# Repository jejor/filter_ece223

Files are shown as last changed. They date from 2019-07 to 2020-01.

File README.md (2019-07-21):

# Filter Project for ECE223PSU/MCECS-2019

This repo contains information pertaining to a four branch 6th order passive Butterworth filters, with volume indicators, music box.
This project was completed to meet the 2018-2019 Electrical Engineering 221-223 sequence course requirements taught by Dr. Donald Duncan at Portland State University Maseeh College of Engineering and Computer Science - Electrical Engineering Program. 

View the project final report [here](/docs/finalreport.pdf) or by using the [google doc link](https://docs.google.com/document/d/1vV6OJEWidjzbffv2h6qe4K4YXA2pBC030I1_OhE0v94/edit?usp=sharing)

Note: Github documentation is currently in progress. Refer to the doc/finalreport.pdf until github documentation is completed.

FilterComplete

# Filter Project Information

## Project Purpose

The function of this project is to filter an audio signal and indicate, by light, the filtered frequency presence. The audio signal is filtered through four branches, each filter branch has its own adjustable volume/LED indicator which is activated when a signal passes through the filter branch. Below is the block diagram for the circuit design,

Fblockdiagram

## Project Parts

### [Audio/Input Signal](/docs/input_signal.md)

The audio signal (input signal) must fall within human range of hearing (typically 20-20000 Hz). The input into the system is a 3.5mm auxiliary audio connection. The audio is split into a stereo (binaural) and a mono (mixed) branch. The audio system design ensures that the music played over the speakers is kept separate as left and right audio channels and the filtered signal contains all the audio data. The audio data splits are made using NE5532 op amps used as buffers.

Note: The signal input is connected via screw terminal which allows for signal input modularity. Therefore, the 3.5mm auxiliary cable input into the filter branches and following volume indicator circuit can be removed to insert different signal generator.

### [Filter Branches](/docs/filters.md)

There are four 6th order passive Butterworth equal termination filters; one low-pass, two band-passes, and a high pass. These filters are routied and mounted on a custom designed PCB.

Note: 
- Low-Pass: < 200 Hz
- Band-Pass 1: 250 Hz to 4 kHz
- Band-Pass 2: 4.05 kHz to 9.95 kHz
- High-Pass: > 10 kHz

### [Volume Indicators](/docs/volume.md)

At the end of each filter branch is a LED volume indicator circuit. These circuits contain a series of LEDs and an LM3915 (resistor and comparator network). This circuit is used to indicate when an audio signal satisfies the filter frequencies and passes through that branch; the LM3915 is used to indicate the intensity (i.e. volume) of the signal. These circuits will have the display of two rows of 5 green, 3 yellow, and 2 red LEDs, totalling 20 LEDs per branch. There are a total of four volume indicators, each receiving an amplified signal from a filter.  The intensity of each volume indicator is controllable via a potentiometer controlling the gainstage on its respective filter. These circuits were routed and mounted on a custom designed PCB.

### [Power System](/docs/power.md)

Power Requirements:
- Op Amps, +18V and -18V
- LM3915, 12-20V
- LEDs, 3-5V
- Common Ground

To satisfy the power requirements the project uses a total of seven 9V batteries. These seven batteries are split between three battery packs with a common ground. The first battery pack powers all the op amp rails, it is four 9V batteries in series with a voltage divider to define a common ground and supply the +18V and -18V. The second battery pack powers the volume indicator circuit main power and contains two 9V batteries in series to supply +18V. The third battery pack powers the LEDs in the volume indicator circuit by using a single 9V and an LM317 voltage regulator to supply 3.3V.

### [Housing](/housing/README.md)

This project is housed within a pressed wood frame.

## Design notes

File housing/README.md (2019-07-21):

# Housing

The housing was designed using AutoDesk Fusion360 where each side was exported to .dxf file type. These files were then imported to RDWorks and then cut using a QD-1390 laser cutter.

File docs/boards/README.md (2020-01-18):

# EAGLE Boards

Made using EAGLE 9.3.2

There are two boards and schematic pairs in this folder. 

- lm3915LEDv.1.brd and lm3915LEDv.1.sch were both designed and manufacutured by Jennifer Jordan on May 2nd, 2019.
- filterboardsSMD-3.brd and filterboardsSMD-3.sch were both designed and manufactured by David Lay (dalay@pdx.edu) on May 29th, 2019.

The completed boards can be seen below,

- lm3915LEDv.1 Front
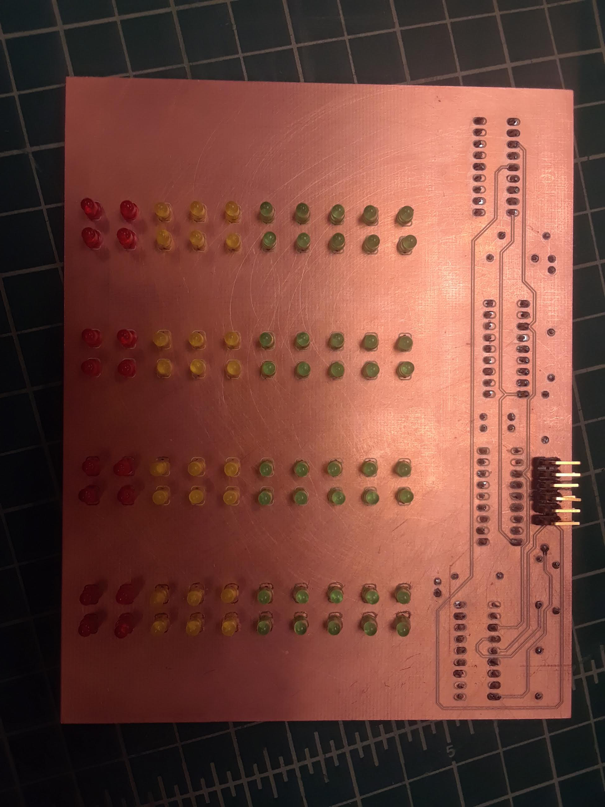
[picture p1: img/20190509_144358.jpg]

- Back
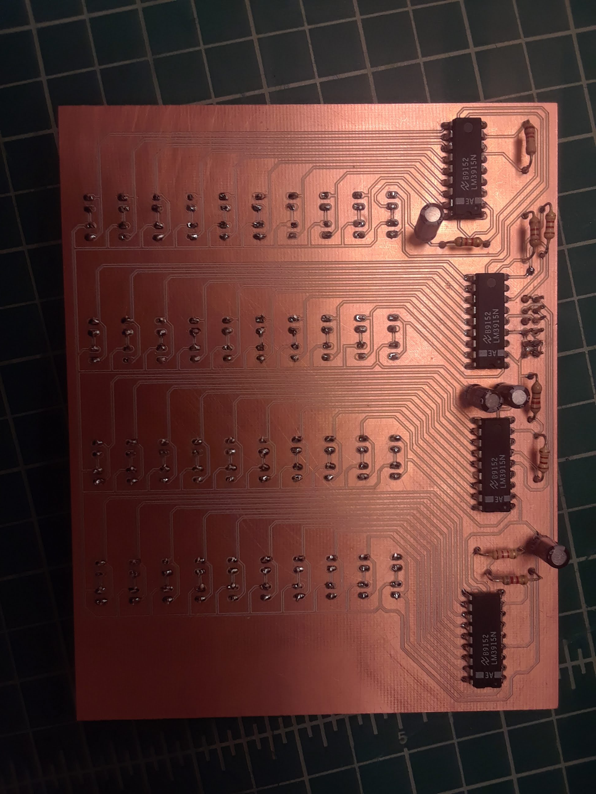
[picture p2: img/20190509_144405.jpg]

- filterboardsSMD-3 Front (credit: David Lay)
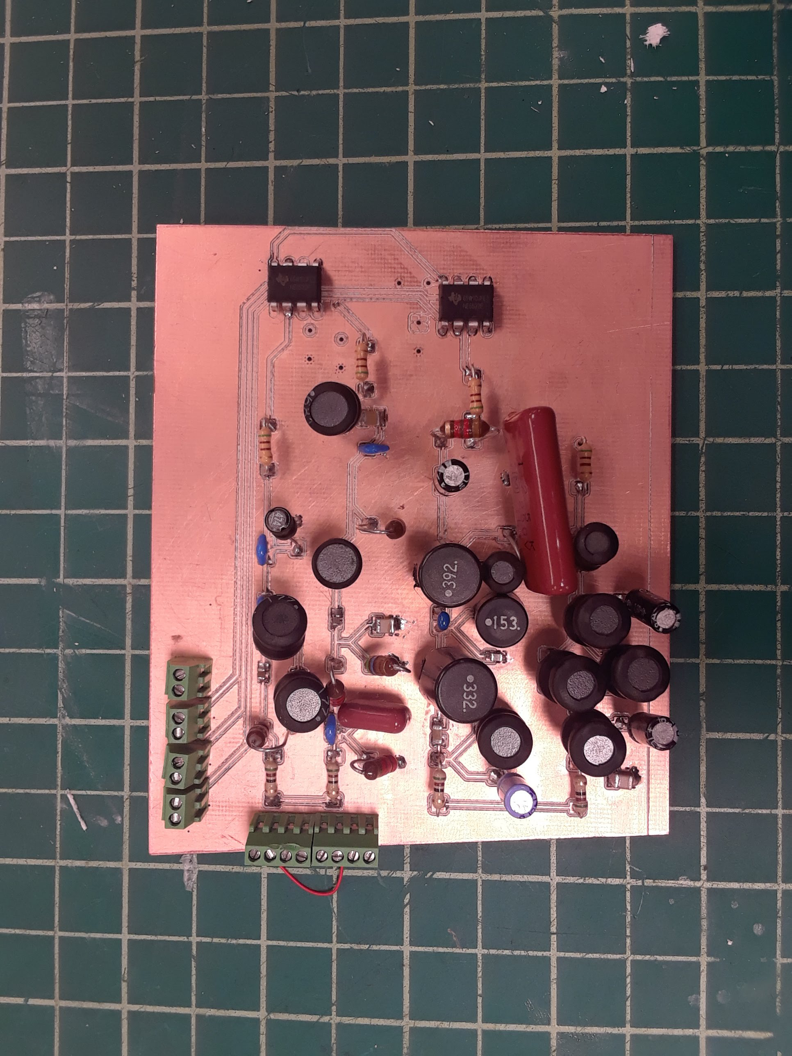
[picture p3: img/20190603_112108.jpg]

- Back (credit: David Lay)
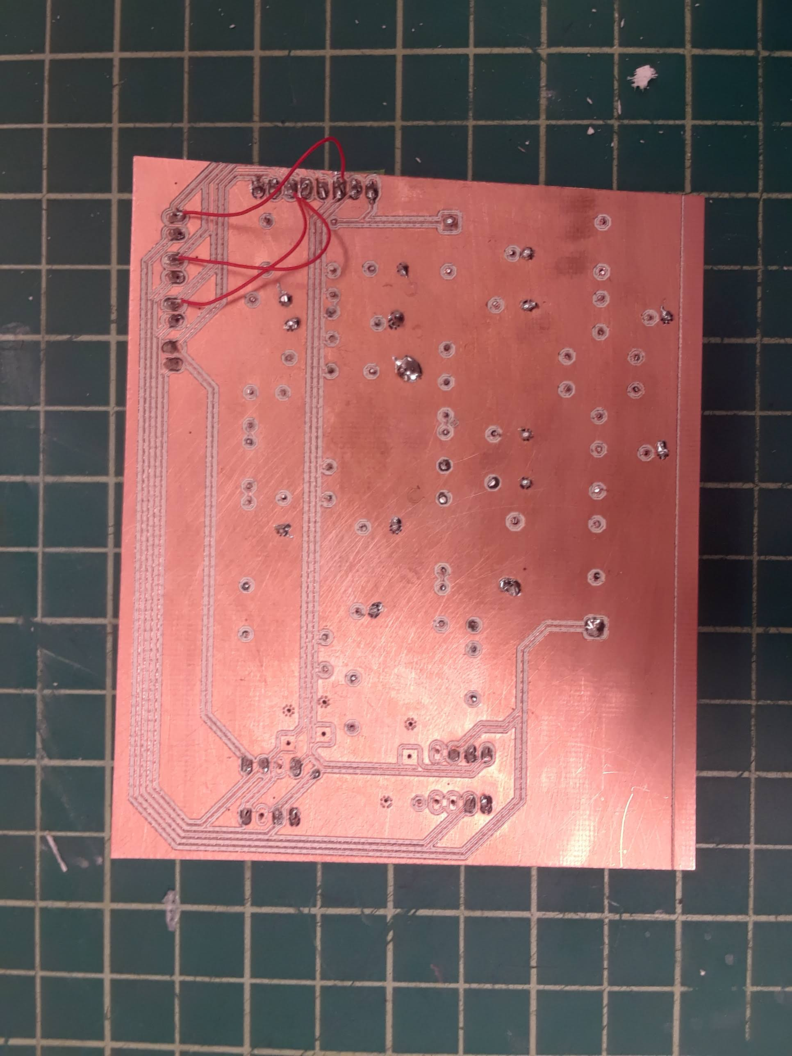
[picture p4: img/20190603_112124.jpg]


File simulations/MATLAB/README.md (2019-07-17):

# MATLAB Simulations

## Low-Pass Filter (< 200 Hz)

[Component Calculations](/simulations/MATLAB/Low_Pass/LPcomponentCalcs.md)

[Transfer Function Calculations](/simulations/MATLAB/Low_Pass/LPtf.md)

[MATLAB Code](/simulations/MATLAB/Low_Pass/LPml.m)

[Linear Analysis Results](/simulations/MATLAB/Low_Pass/LPla.pdf)

## Band-Pass 1 Filter (250 Hz - 4 kHz)

[Component Calculations](/simulations/MATLAB/Band_Pass1/BP1componentCalcs.md)

[Transfer Function Calculations](/simulations/MATLAB/Band_Pass1/BP1tf.md)

[MATLAB Code](/simulations/MATLAB/Band_Pass1/BP1ml)

[Linear Analysis Results](/simulations/MATLAB/Band_Pass1/BPla.pdf)

## Band-Pass 2 Filter (4.05 kHz - 9.95 kHz)

[Component Calculations](/simulations/MATLAB/Band_Pass2/BP2componentCalcs.md)

[Transfer Function Calculations](/simulations/MATLAB/Band_Pass2/BP2tf.md)

[MATLAB Code](/simulations/MATLAB/Band_Pass2/BP2ml)

[Linear Analysis Results](/simulations/MATLAB/Band_Pass2/BP2la.pdf)

## High-Pass Filter (> 10 kHz)

[Component Calculations](/simulations/MATLAB/High_Pass/HPcomponentCalcs.md)

[Transfer Function Calculations](/simulations/MATLAB/High_Pass/HPtf.md)

[MATLAB Code](/simulations/MATLAB/High_Pass/HPml.m)

[Linear Analysis Results](/simulations/MATLAB/High_Pass/HPla.pdf)

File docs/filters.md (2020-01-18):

# Filter Branches

There are four filters used in this circuit, one low-pass, one high pass, and two band-pass. All four filters are 6th order passive Butterworth equal termination filters. The low-pass filter has a set cutoff frequency of 200 Hz, the first band-pass filter has a set pass band between 250 Hz to 4 kHz, the second band-pass filter has a set pass band between 4.05 kHz to 9.95 kHz, and the high-pass filter has a set frequency cutoff of 10 kHz. At the output of each filter there is an operational amplifier with an adjustable gain (using a potentiometer). Per the LTspice simulations, the gain for this op amp should indicate no filter signal output to a maximum gain of 200. With the real component values, all four filter branches have less than a 7% difference from the set cutoff frequencies. These circuits were routed and assembled on a PCB.

For More info see the filter diagrams [here](docs/boards/README.md)

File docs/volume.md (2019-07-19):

# Volume Indicator Circuit

At the end of each filter branch is a LED volume indicator circuit. These circuits contain a series of LEDs and an [LM3915](http://pdf.datasheetcatalog.com/datasheet/nationalsemiconductor/DS005104.PDF) (resistor and comparator network). This circuit is used to indicate when an audio signal satisfies the filter frequencies and passes through that branch; the LM3915 is used to indicate the intensity (i.e. volume) of the signal. 

These circuits have the display of two rows of 5 green, 3 yellow, and 2 red LEDs, totalling 20 LEDs per branch and a total of 80 LEDs for the full circuit. There are four volume indicators, each receiving an amplified signal from a filter.  The intensity of each volume indicator is controllable via a potentiometer controlling the gainstage on its respective filter. These circuits were routed and mounted on a custom designed PCB.

volumeindicatorschematic

volumeindicatorboard

volumeindicatorpcbfront

volumeindicatorpcbback

## Power Pack

This circuit is powered by [power pack 2](/docs/power.md) which supplies +18V to the four LM3915 and also supplies +3.3V to the 80 LEDs.

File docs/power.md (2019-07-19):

# Power System

Due to project deadlines, the current power system for this project has a lot of room for improvement. The system design meets all the power requirements but the efficiency could be improved. To satisfy the power requirements the project uses a total of seven 9V batteries. These seven batteries are split between three battery packs with a common ground. 

The power requirements are as follows:

- Eight NE5532 op amps which require +18V and -18V
- Four LM3915s which require 12-20V
- Four LED rows totalling 80 LEDs which require 3-5V

The first battery pack powers all the op amp rails, it is four 9V batteries in series with a voltage divider to define a common ground and supply the +18V and -18V, see the circuit diagram below.

powerpack1

The second battery pack powers the volume indicator circuit main power and contains two 9V batteries in series to supply +18V. There is also a power switch mounted to the housing that is placed within this circuit. The power switch has three states, I, Off, and II. There is a diode, 1N4148, which prevents the mode from being triggered when I is selected and allows the mode to be changed when selecting II, see below.

powerpack2

The third battery pack powers the LEDs in the volume indicator circuit by using a single 9V and an LM317 voltage regulator to supply 3.3V. The equation used to calculate the Vout value of the LM317 is Vout=1.25*(1+R2R1). The resistor values were calculated using the prior equation where R1=110 and R2=180.

powerpack3

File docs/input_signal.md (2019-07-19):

# Audio/Input Signal 

The audio is fed through a 3.5mm auxillary cable and is split into a stereo (binaural) and a mono (mixed) branch. The audio system design ensures that the music played over the speakers is kept separate as left and right audio channels and the filtered signal contains all the audio data. The audio data splits are made using [NE5532](http://www.ti.com/lit/ds/symlink/ne5532.pdf) op amps used as buffers.

audiodiagram

To filter an audio signal (using the above circuit) the mono-signal is fed into pin 8 in the below diagram,

signalinputdiagram

It can be seen that the input signal to the filter circuit is interchangable using the terminal block as the signal input,

signalinputphoto

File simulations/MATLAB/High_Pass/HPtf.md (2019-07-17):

## High Pass Transfer Function Calculation

Given the Factors of Polynomials for 6th order filters, 

Factors_of_Polynomials

the following transfer function for high-pass filter was calculated,
	HLP(s)=G0B6(s), where G0=1
	HLP(s)=1(s2+0.5176s+1)(s2+1.4142s+1)(s2+1.9319s+1)
Next, the transfer function for the high-pass is calculated given the LPF-to-HPF transformation where the band-pass filter transfer function is H(cs) and c=10000*2= 62831.85 rad/s. Such that, 
	cs=62831.85s
	HHP(s)=s9s9+2.428e05s8+2.947e10s7+2.268e15s6+1.163e20s5+3.784e24s4+6.153e28s3

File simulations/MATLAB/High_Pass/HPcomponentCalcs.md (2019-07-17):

## High-Pass Component Calculations

The high-pass filter in this circuit is a 6th order Butterworth equal termination filter. 
The cutoff frequency is set to 10 kHz. 
Given the Butterworth equal termination High-Pass Prototype Element chart, 

High_Pass_Prototype_Element_Chart

and the following diagram,

High_Pass_Basic_Diagram

Where, RS=RL=50  and fc=10000 Hz the following component values are calculated,

Ideal Component Values
Real Component Values
L1
1.535883 mH
1.8 mH
C2
225 nF
220 nF
L3
412.221 H
220 H+220 H=440 H
C4
165 nF
150 nF
L5
562.626 H
 470  H 
C6
614 nF
 680 nF

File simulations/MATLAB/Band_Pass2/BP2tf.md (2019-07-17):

## Band-Pass 2 Transfer Function Calculations

Given the Factors of Polynomials for 6th order filters, 

Factors_of_Polynomials

the following transfer function for band-pass 2 filter was calculated,
	HLP(s)=G0B6(s), where G0=1
	HLP(s)=1(s2+0.5176s+1)(s2+1.4142s+1)(s2+1.9319s+1)
Next, the transfer function for the band-pass is calculated given the LPF-to-BPF transformation where the band-pass filter transfer function is H(Q(s0+0s)), the Q-factor is Q=0, the resonant frequency is 0=12, the absolute bandwidth is =(2-1), 1=4050*2=25446.9 rad/s, and 2=9950*2=62517.69 rad/s. Such that,
	=(2-1)=62517.69-25446.9=37070.79 rad/s
	0=12=25446.9*62517.69=39885.9 rad/s
	Q=0=39885.937070.79=1.0759
	HBP1(s)=2.555e41s99.842e13s15+1.41e19s14+1.949e24s13+1.58e29s12+1.155e34s11+6.022e38s10
		2.793e43s9+9.58e47s8+2.923e52s7+6.361e56s6+1.248e61s5+1.437e65s4+1.596e69s3

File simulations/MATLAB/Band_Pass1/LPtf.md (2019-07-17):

## Low Pass Transfer Function Calculations

Given the Factors of Polynomials for 6th order filters, 

Factors_of_Polynomials

the following transfer function for the band-pass 1 filter was calculated,
	HLP(s)=G0B6(s), where G0=1
	HLP(s)=1(s2+0.5176s+1)(s2+1.4142s+1)(s2+1.9319s+1)
Next, the transfer function for the band-pass is calculated given the LPF-to-BPF transformation where the band-pass filter transfer function is H(Q(s0+0s)), the Q-factor is Q=0, the resonant frequency is 0=12, the absolute bandwidth is =(2-1), 1=250*2=1570.8 rad/s, and 2=4000*2=25132.74 rad/s. Such that,
	=(2-1)=25132.74-1570.8=23561.94 rad/s
	0=12=1570.8*25132.74=6283.19 rad/s
	Q=0=23561.946283.19=0.267
	HBP1(s)=1.526e34s98.987e07s15+8.171e12s14+3.928e17s13+1.232e22s12+2.665e26s11+3.901e30s10
		3.509e34s9+1.54e38s8+4.153e41s7+7.58e44s6+9.54e47s5+7.836e50s4+3.402e53s3

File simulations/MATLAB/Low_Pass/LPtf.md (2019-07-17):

## Low Pass Transfer Function Calculation

Given the Factors of Polynomials for 6th order filters, 

Factors_of_Polynomials

the following transfer function for the low-pass filter was calculated,
	HLP(s)=G0B6(s), where G0=1,B6(s)=1(s2+0.5176s+1)(s2+1.4142s+1)(s2+1.9319s+1),  andc=2*200=1256.6064 rad/s
	HLP(s)=G0B6(sc)=1((sc)2+0.5176(sc)+1)((sc)2+1.4142(sc)+1)((sc)2+1.9319(sc)+1)
	HLP(s)=1((s1256.6)2+0.5176(s1256.6)+1)((s1256.6)2+1.4142(s1256.6)+1)((s1256.6)2+1.9319(s1256.6)+1)
HLP(s)=12.53636*10-19*s6+1.23201*10-15*s5+2.99159*10-12s4+4.60529*10-9s3+4.72605*10-6s2+0.00307473*s+1

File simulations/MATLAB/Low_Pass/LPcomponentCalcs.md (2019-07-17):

## Low Pass Component Calculations

The flow-pass filter in this circuit is a 6th order Butterworth equal termination filter. The cutoff frequency is 200 Hz. 
Given the Butterworth equal termination Low-Pass Prototype Element chart

Low_Pass_Prototype_Element_Chart
, and the following diagram,

Low_Pass_Basic_Diagram

Where, RS=RL=50  and the following component values are calculated,

Ideal Component Values
Actual Component Values
C1
8.244 F
8.2 F
L2
56.26 mH
56 mH
C3
30.749 F
33 F
L4
76.87 mH
1156 mH+156 mH+56mH = 84 mH
C5
22.5 F
22 F
L6
20.6 mH
22 mH

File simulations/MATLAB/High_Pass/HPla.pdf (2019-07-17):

%Transfer Function Analysis for High-Pass 6th Order Butterworth Filter %ECE223 Sp19, Jennifer Jordan & David Lay

s = tf('s');
x = (62831.85/s); %LP to HP transformation condition
H = 1/((x^2+.5176*x+1)*(x^2+1.4142*x+1)*(x^2+1.9319*x+1)) %Figures:
figure(1);
bode(H);
title('High-Pass Butterworth Filter Bode Plot'); figure(2);
impulse(H);
title('High-Pass Butterworth Filter Impulse Response'); figure(3);
step(H);
title('High-Pass Butterworth Filter Step Response'); figure(4);
pzplot(H);
title('High-Pass Butterworth Filter Pole-Zero Plot');

H =

s^9

s^9 + 2.428e05 s^8 + 2.947e10 s^7 + 2.268e15 s^6 + 1.163e20 s^5

+ 3.784e24 s^4 + 6.153e28
s^3

Continuous-time transfer function.

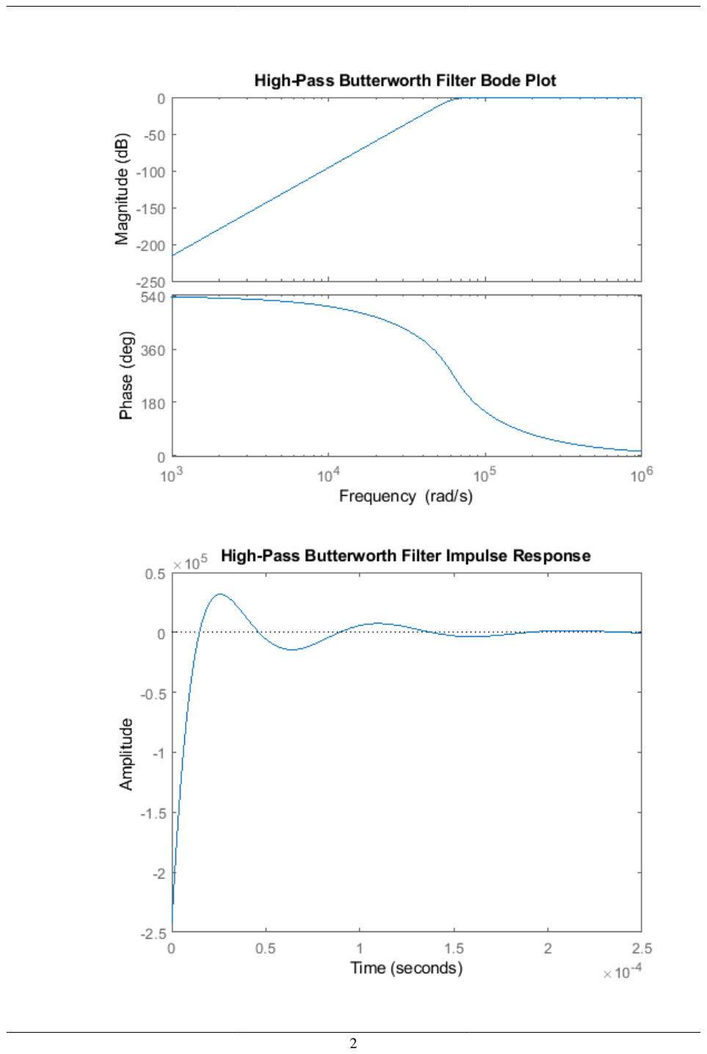
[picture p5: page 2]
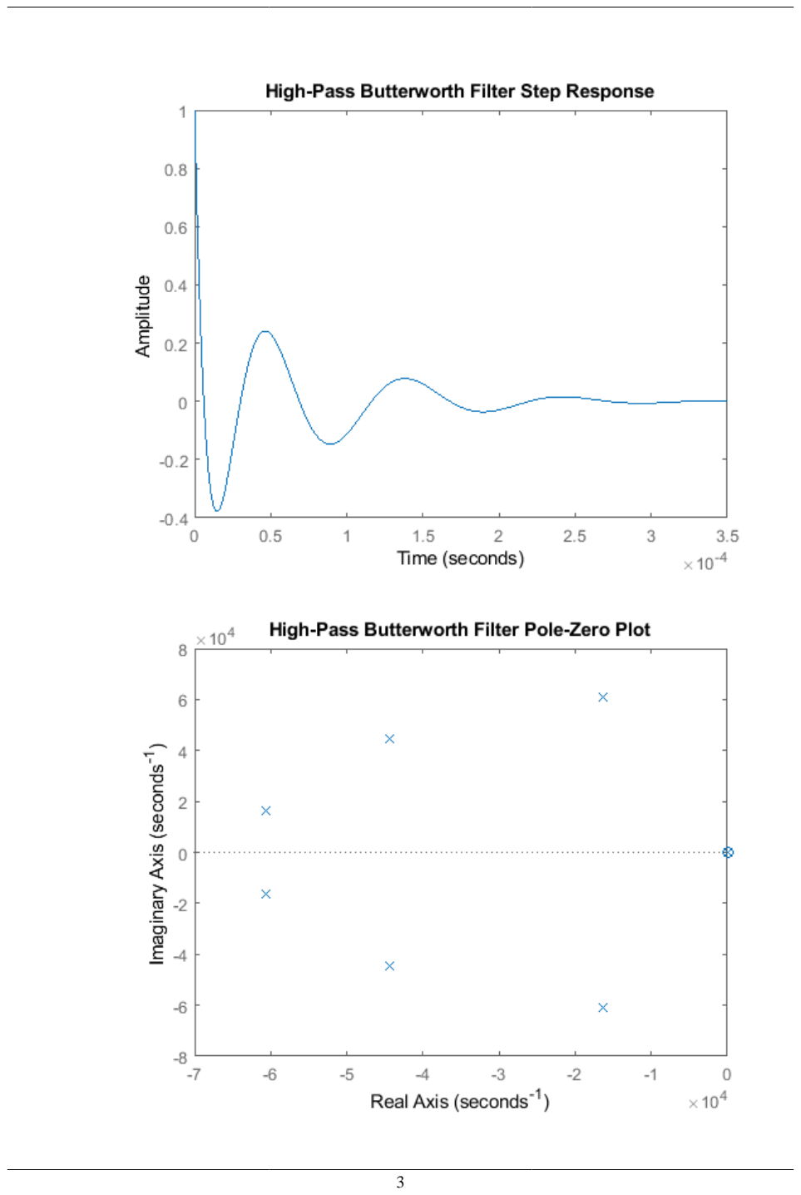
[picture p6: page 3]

Published with MATLAB® R2018b

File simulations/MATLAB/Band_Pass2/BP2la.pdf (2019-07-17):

%Transfer Function Analysis for Band-Pass 2 6th Order Butterworth Filter
%ECE223 Sp19, Jennifer Jordan & David Lay

s = tf('s');
x = (1.0759*((s/39885.9)+(39885.9/s))); %LP to BP transformation condition
H = 1/((x^2+.5176*x+1)*(x^2+1.4142*x+1)*(x^2+1.9319*x+1)) %Figures:
figure(1);
bode(H);
title('Band-Pass 2 Butterworth Filter Bode Plot'); figure(2);
impulse(H);
title('Band-Pass 2 Butterworth Filter Impulse Response'); figure(3);
step(H);
title('Band-Pass 2 Butterworth Filter Step Response'); figure(4);
pzplot(H);
title('Band-Pass 2 Butterworth Filter Pole-Zero Plot');

H =

2.555e41 s^9

9.842e13 s^15 + 1.41e19 s^14 + 1.949e24 s^13 + 1.58e29 s^12 +
1.155e34 s^11

+ 6.022e38 s^10 + 2.793e43 s^9 + 9.58e47 s^8 + 2.923e52 s^7

+ 6.361e56 s^6 + 1.248e61 s^5 + 1.437e65 s^4 + 1.596e69 s^3

Continuous-time transfer function.

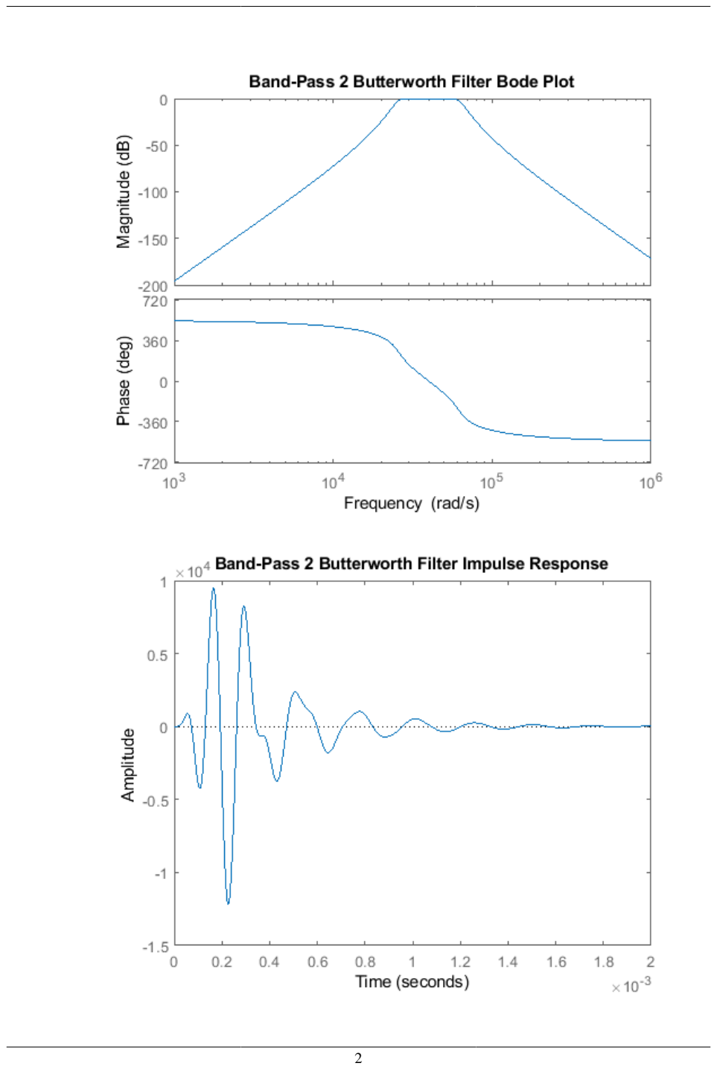
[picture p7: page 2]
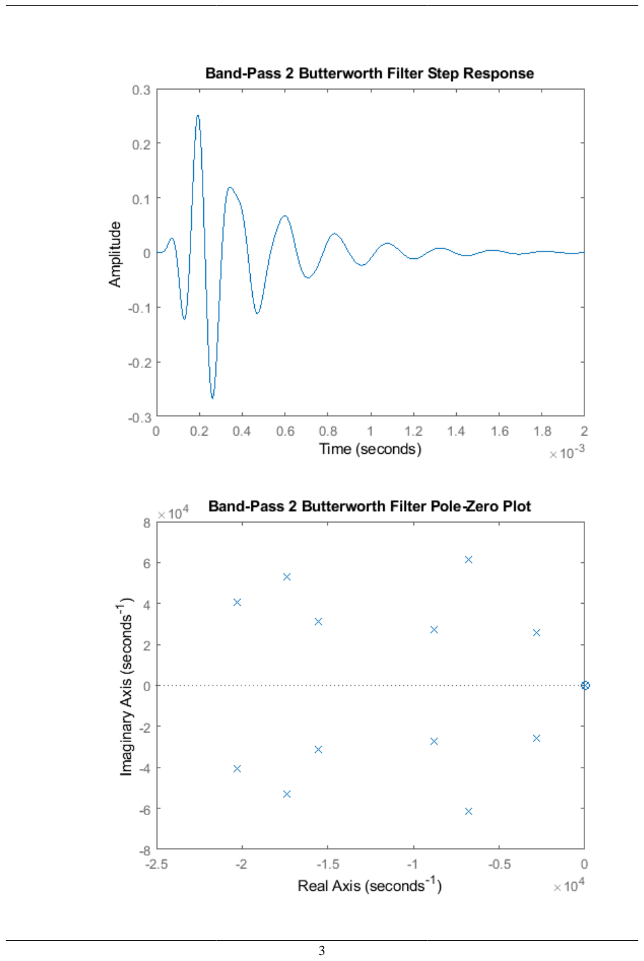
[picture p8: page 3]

Published with MATLAB® R2018b

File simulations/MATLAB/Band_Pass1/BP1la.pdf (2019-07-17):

%Transfer Function Analysis for Band-Pass 1 6th Order Butterworth Filter
%ECE223 Sp19, Jennifer Jordan & David Lay

s = tf('s');
x = (.267*((s/6283.19)+(6283.19/s))); %LP to HP transformation condition
H = 1/((x^2+.5176*x+1)*(x^2+1.4142*x+1)*(x^2+1.9319*x+1)) %Figures:
figure(1);
bode(H);
title('Band-Pass 1 Butterworth Filter Bode Plot'); figure(2);
impulse(H);
title('Band-Pass 1 Butterworth Filter Impulse Response'); figure(3);
step(H);
title('Band-Pass 1 Butterworth Filter Step Response'); figure(4);
pzplot(H);
title('Band-Pass 1 Butterworth Filter Pole-Zero Plot');

H =

1.526e34 s^9

8.987e07 s^15 + 8.171e12 s^14 + 3.928e17 s^13 + 1.232e22 s^12

+ 2.665e26 s^11 + 3.901e30 s^10 + 3.509e34 s^9 + 1.54e38 s^8

+ 4.153e41 s^7 + 7.58e44 s^6 + 9.54e47 s^5 + 7.836e50 s^4

+ 3.402e53
s^3

Continuous-time transfer function.

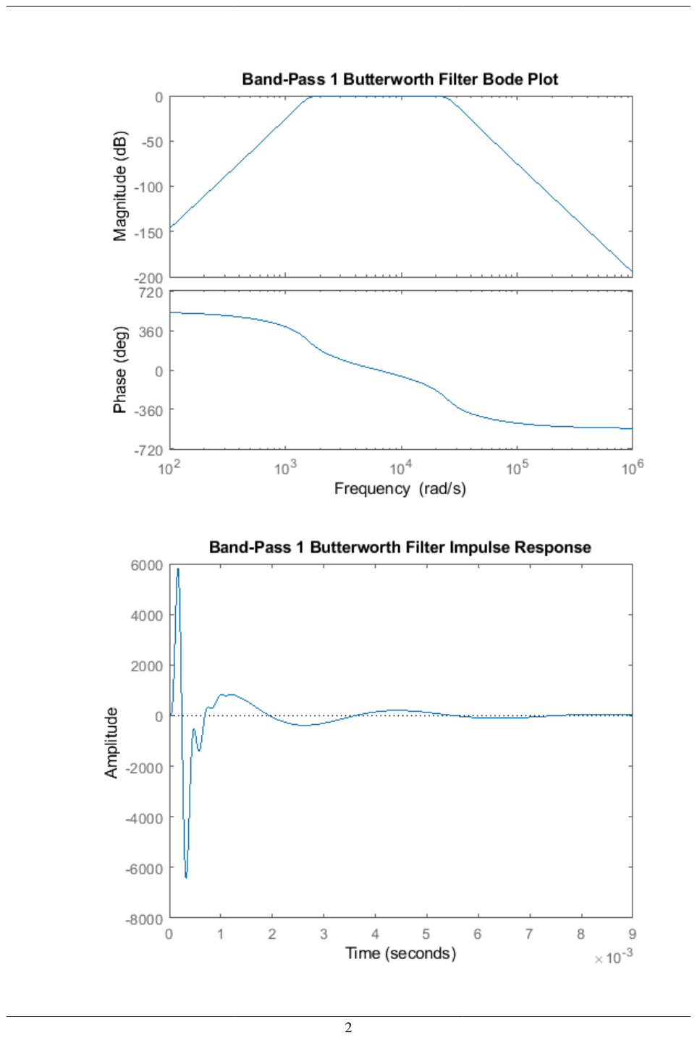
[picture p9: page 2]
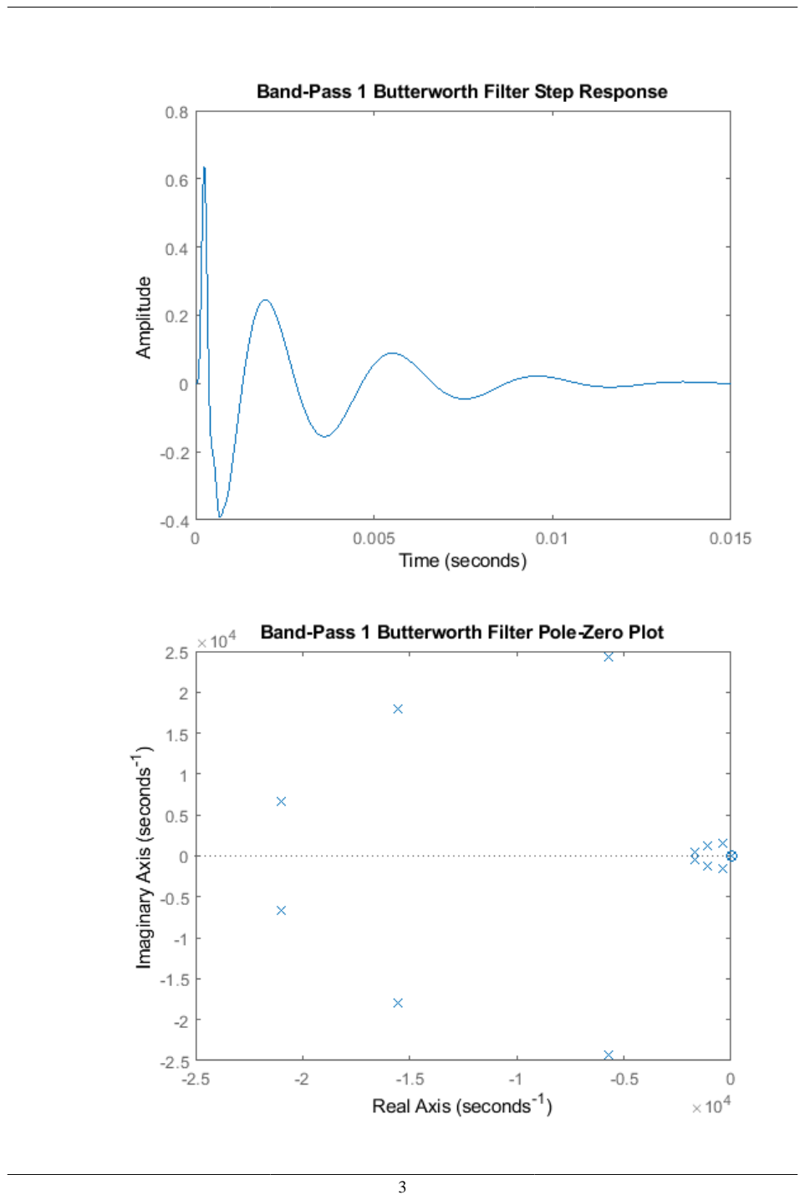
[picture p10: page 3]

Published with MATLAB® R2018b

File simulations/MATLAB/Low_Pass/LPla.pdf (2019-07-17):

%Transfer Function Analysis for High-Pass 6th Order Butterworth Filter %ECE223 Sp19, Jennifer Jordan & David Lay
s = tf('s');
H = 1/
(2.53636*10^-19*s^6+1.23201*10^-15*s^5+2.99159*10^-12*s^4+4.60529*10^-9*s^3+4.72605*10^-6*s^2+0.00307473*s +1)

%Figures:
figure(1);
bode(H);
title('Low-Pass Butterworth Filter Bode Plot'); figure(2);
impulse(H);
title('Low-Pass Butterworth Filter Impulse Response'); figure(3);
step(H);
title('Low-Pass Butterworth Filter Step Response'); figure(4);
pzplot(H);
title('Low-Pass Butterworth Filter Pole-Zero Plot');

H =

1

2.536e-19 s^6 + 1.232e-15 s^5 + 2.992e-12 s^4 + 4.605e-09 s^3

+ 4.726e-06 s^2 + 0.003075 s + 1

Continuous-time transfer function.

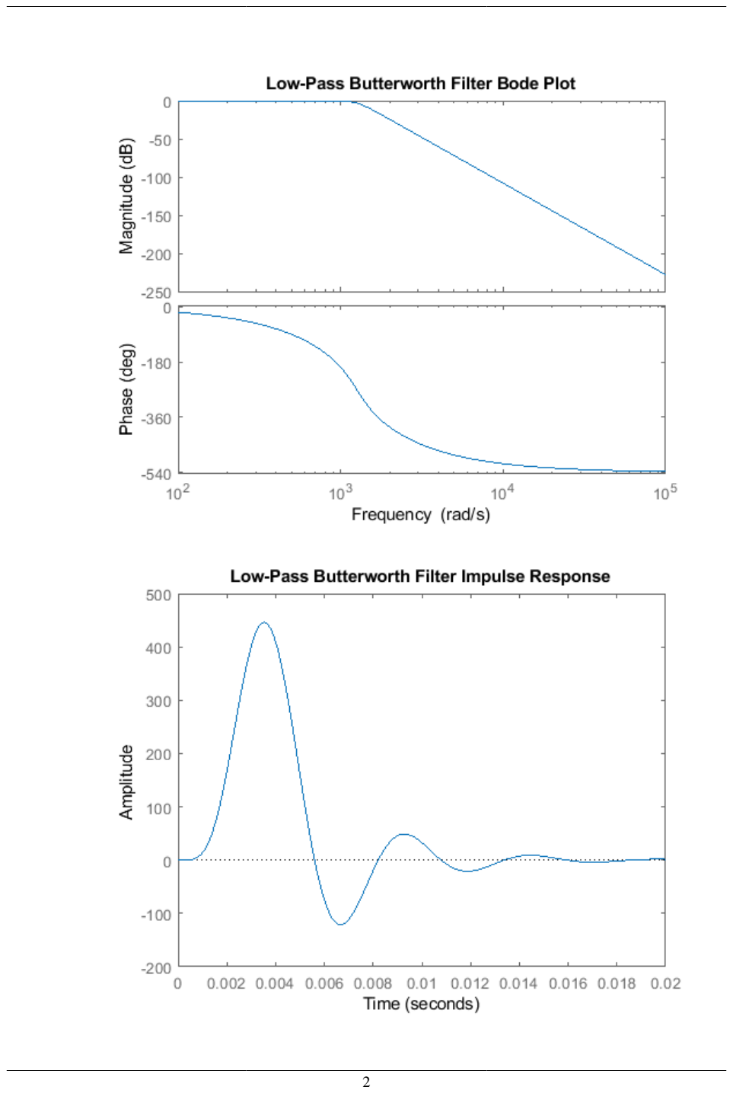
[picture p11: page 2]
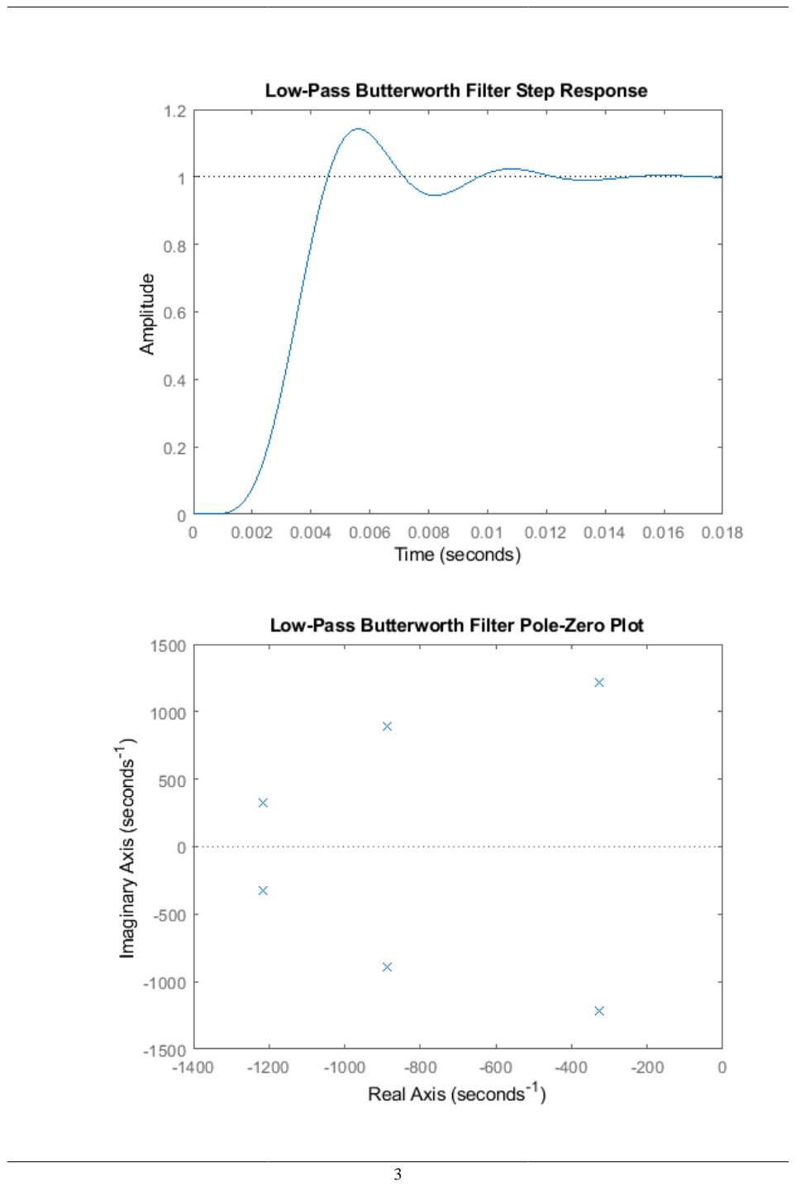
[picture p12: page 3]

Published with MATLAB® R2018b

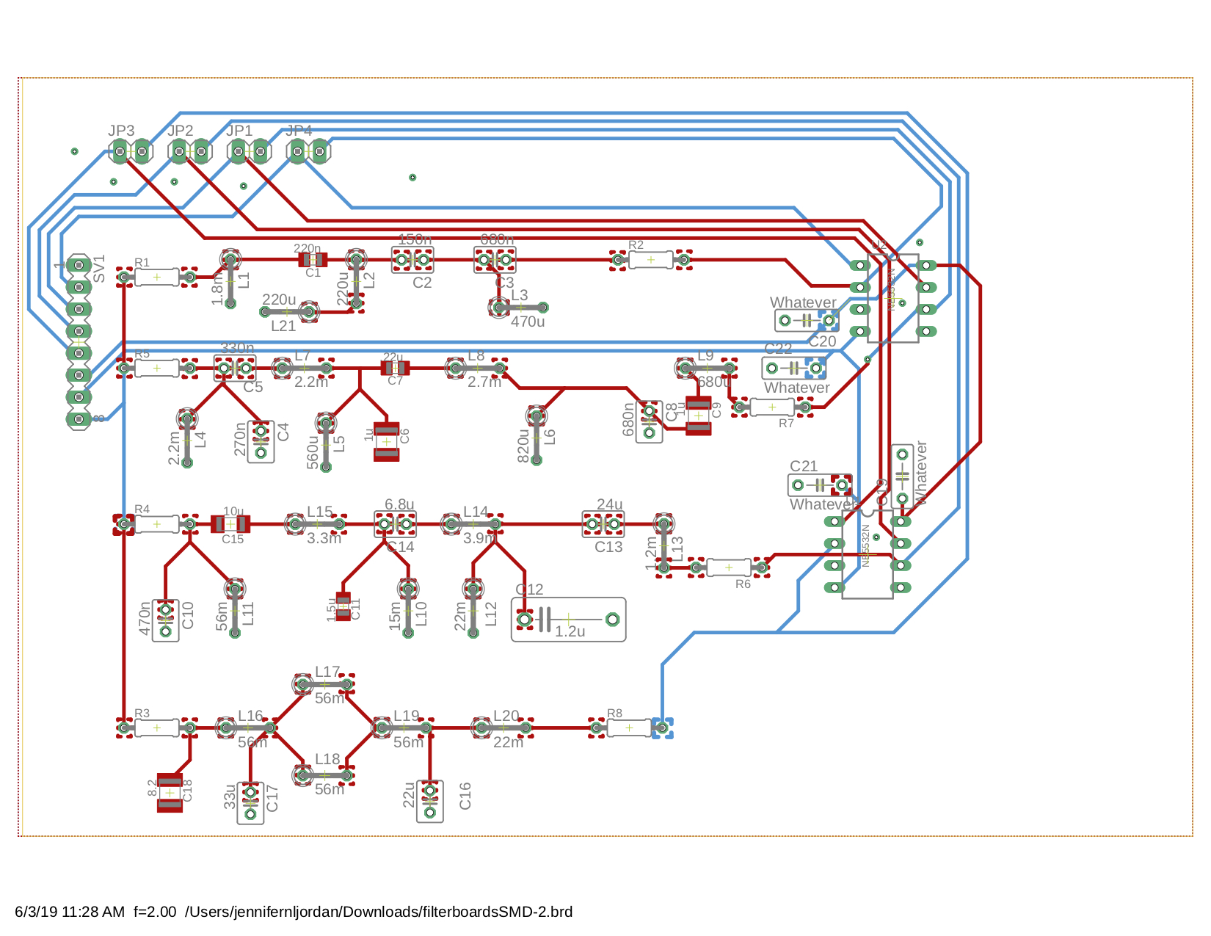
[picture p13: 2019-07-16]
diagrams/filter_board/filterboardsSMD-2.jpg

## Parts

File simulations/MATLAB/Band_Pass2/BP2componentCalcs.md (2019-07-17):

## Band-Pass 2 Component Calculations

The second band-pass filter in this circuit is a 6th order Butterworth equal termination filter. 
The band-pass frequency band is between 4.05 kHz - 9.95 kHz. 
Given the Butterworth equal termination Band-Pass Prototype Element chart, 

Band_Pass_Prototype_Element_Chart

and the following diagram,

Band_Pass_Basic_Diagram

Where, RS=RL=50 , fc=4050*9950=6348 Hz, and =9950-40506348=0.929426591 the following component values are calculated,

Ideal Component Values
Actual Component Values
L1
2.248724 mH
2.2 mH
C1
279 nF
270 nF
L2
1.907208 mH
2.2 mH
C2
330 nF
330 nF
L3
603.544 H
560 H
C3
1.042 F
1 F
L4
2.605889 mH
2.7 mH
C4
241 nF
220 nF
L5
823.755 H
820 H 
C5
763 nF
680 nF
L6
698.68 H
680 H
C6
900 nF
1 F

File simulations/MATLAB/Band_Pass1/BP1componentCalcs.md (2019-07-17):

## Band Pass 1 Component Calculations

The first band-pass filter in this circuit is a 6th order Butterworth equal termination filter. 
The band-pass frequency band is between 250 Hz - 4 kHz. 
Given the Butterworth equal termination Band-Pass Prototype Element chart, 

Band_Pass_Prototype_Element_Chart

and the following diagram,

Band_Pass_Basic_Diagram

Where, RS=RL=50 , fc=250*4000=1000 Hz, and =4000-2501000=3.75 the following component values are calculated,
Ideal Component Values
Actual Component Values
L1
57.5956 mH
56 mH
C1
440 nF 
470 nF
L2
3.000674 mH
3.3 mH
C2
8.439 F 
10 F
L3
15.458301 mH
15 mH
C3
1.64 F
1.5 F
L4
4.099931 mH 
3.9 mH
C4
6.183 F 
6.8 F
L5
21.098492 mH 
22 mH
C5
1.2F 
1.2 F
L6
1.099257 mH 
1.2 mH
C6
23.062 F 
24 F

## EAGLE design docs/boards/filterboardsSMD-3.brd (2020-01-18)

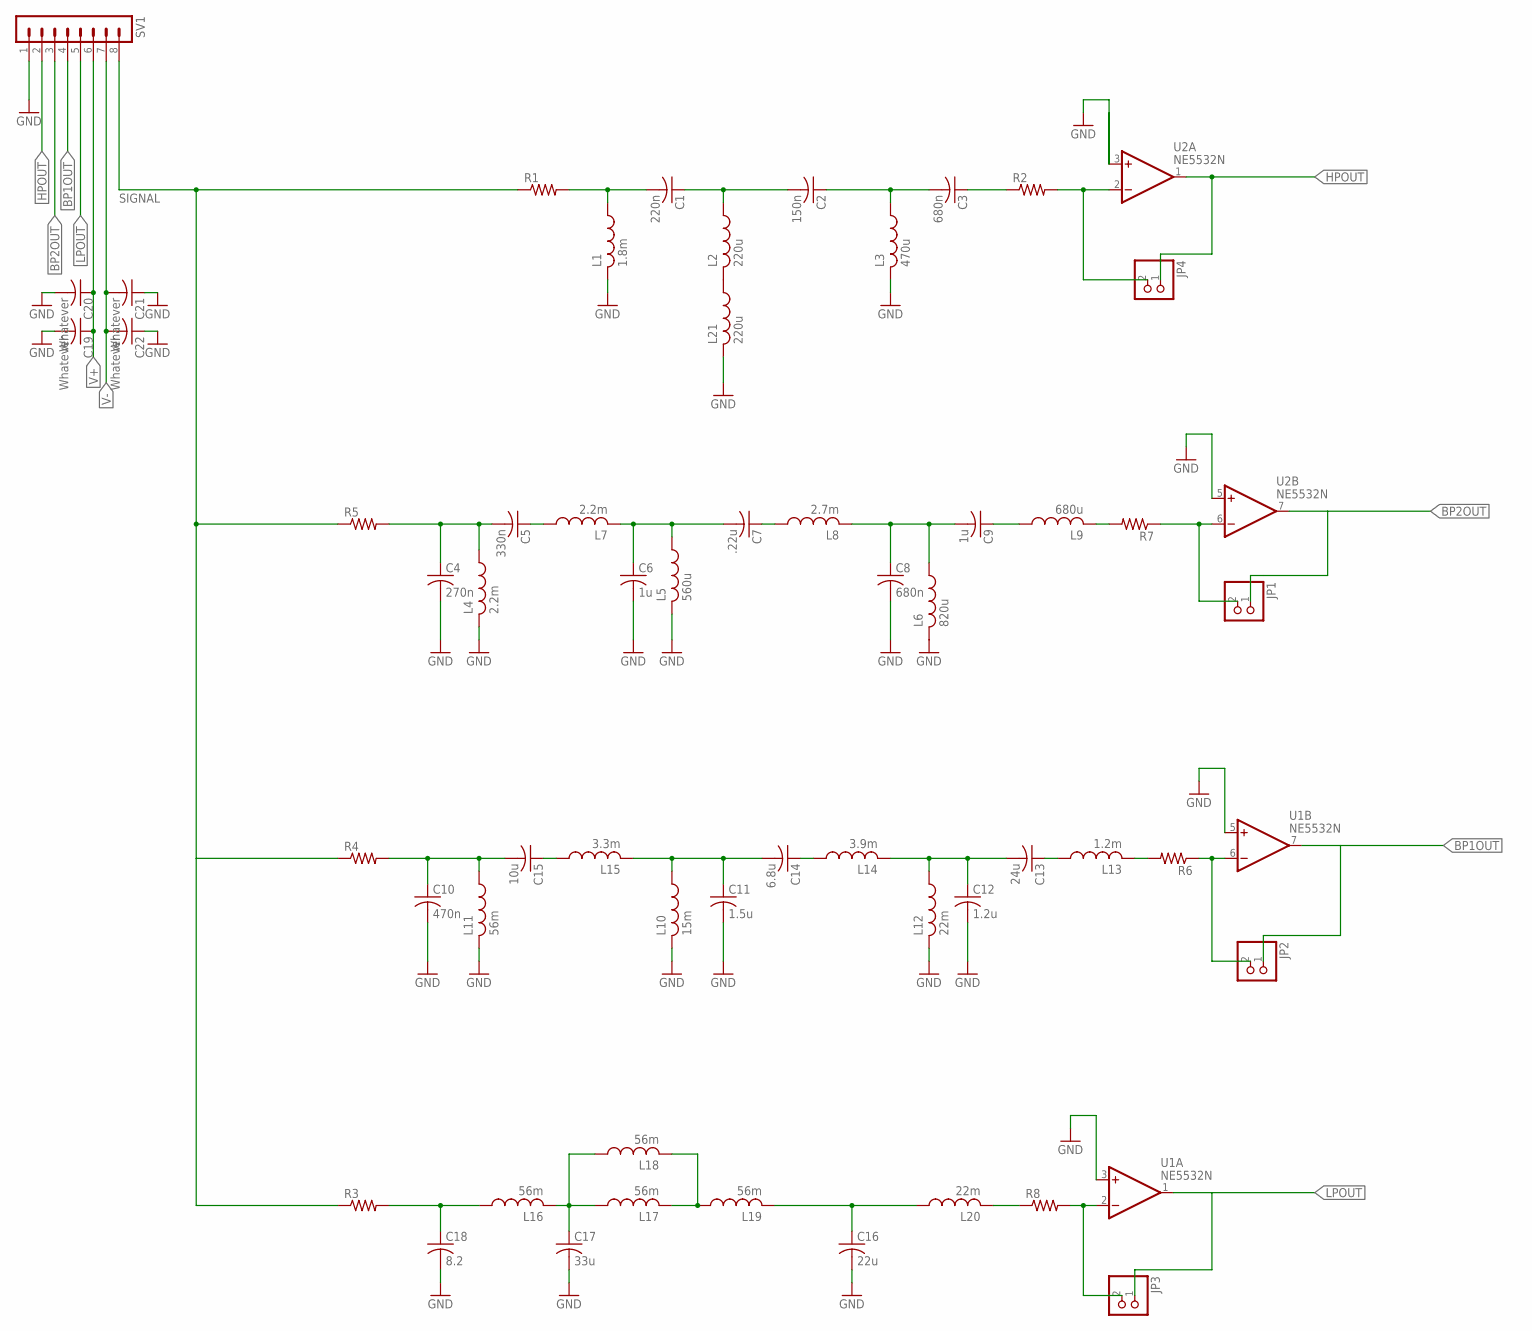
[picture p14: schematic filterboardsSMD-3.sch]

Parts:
C1: 220n; C0805K
C2: 150n; C025-030X050
C3, C8: 680n; C025-030X050
C4: 270n; C025-030X050
C5: 330n; C025-030X050
C6, C9: 1u; C1210K
C7: .22u; C0805K
C10: 470n; C025-030X050
C11: 1.5u; C0805K
C12: 1.2u; C102-054X133
C13: 24u; C025-030X050
C14: 6.8u; C025-030X050
C15: 10u; C1206K
C16: 22u; C025-030X050
C17: 33u; C025-030X050
C18: 8.2; C1210K
C19, C20, C21, C22: Whatever; C050-025X075
JP1, JP2, JP3, JP4: PINHD-1X2; 1X02
L1: 1.8m; 0207/5V
L2, L21: 220u; 0207/5V
L3: 470u; 0207/5V
L4, L7: 2.2m; 0207/5V
L5: 560u; 0207/5V
L6: 820u; 0207/5V
L8: 2.7m; 0207/5V
L9: 680u; 0207/5V
L10: 15m; 0207/5V
L11, L16, L17, L18, L19: 56m; 0207/5V
L12, L20: 22m; 0207/5V
L13: 1.2m; 0207/5V
L14: 3.9m; 0207/5V
L15: 3.3m; 0207/5V
R1, R2, R3, R4, R5, R6, R7, R8: R-US_0204/7; 0204/7
SV1: MA08-1
U1, U2: NE5532N; DIL08

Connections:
BP1OUT: JP2.1, SV1.4, U1.7 (OUT)
BP2OUT: JP1.1, SV1.3, U2.7 (OUT)
GND: C4.2, C6.2, C8.2, C10.2, C11.2, C12.2, C16.2, C17.2, C18.2, C19.2, C20.2, C21.1, C22.1, L1.2, L3.2, L4.2, L5.2, L6.2, L10.2, L11.2, L12.2, L21.2, SV1.1, U1.3 (+IN), U1.5 (+IN), U2.5 (+IN)
HPOUT: JP4.1, SV1.2, U2.1 (OUT)
LPOUT: JP3.1, SV1.5, U1.1 (OUT)
unnamed: C1.2, L1.1, R1.2
unnamed: C1.1, C2.2, L2.1
unnamed: C2.1, C3.2, L3.1
unnamed: C3.1, R2.1
unnamed: C4.1, C5.2, L4.1, R5.2
unnamed: C5.1, L7.1
unnamed: C6.1, C7.2, L5.1, L7.2
unnamed: JP3.2, R8.2, U1.2 (-IN)
unnamed: C7.1, L8.1
unnamed: C8.1, C9.2, L6.1, L8.2
unnamed: C9.1, L9.1
unnamed: JP2.2, R6.1, U1.6 (-IN)
unnamed: JP1.2, R7.1, U2.6 (-IN)
unnamed: L9.2, R7.2
unnamed: JP4.2, R2.2, U2.2 (-IN)
unnamed: C10.1, C15.2, L11.1, R4.2
unnamed: C15.1, L15.1
unnamed: C11.1, C14.2, L10.1, L15.2
unnamed: L2.2, L21.1
unnamed: C14.1, L14.1
unnamed: C12.1, C13.2, L12.1, L14.2
unnamed: C13.1, L13.1
unnamed: L13.2, R6.2
unnamed: C18.1, L16.1, R3.2
unnamed: C17.1, L16.2, L17.1, L18.1
unnamed: L17.2, L18.2, L19.1
unnamed: C16.1, L19.2, L20.1
unnamed: L20.2, R8.1
SIGNAL: R1.1, R3.1, R4.1, R5.1, SV1.8
V+: C19.1, C20.1, SV1.6, U1.8 (V+), U2.8 (V+)
V-: C21.2, C22.2, SV1.7, U1.4 (V-), U2.4 (V-)

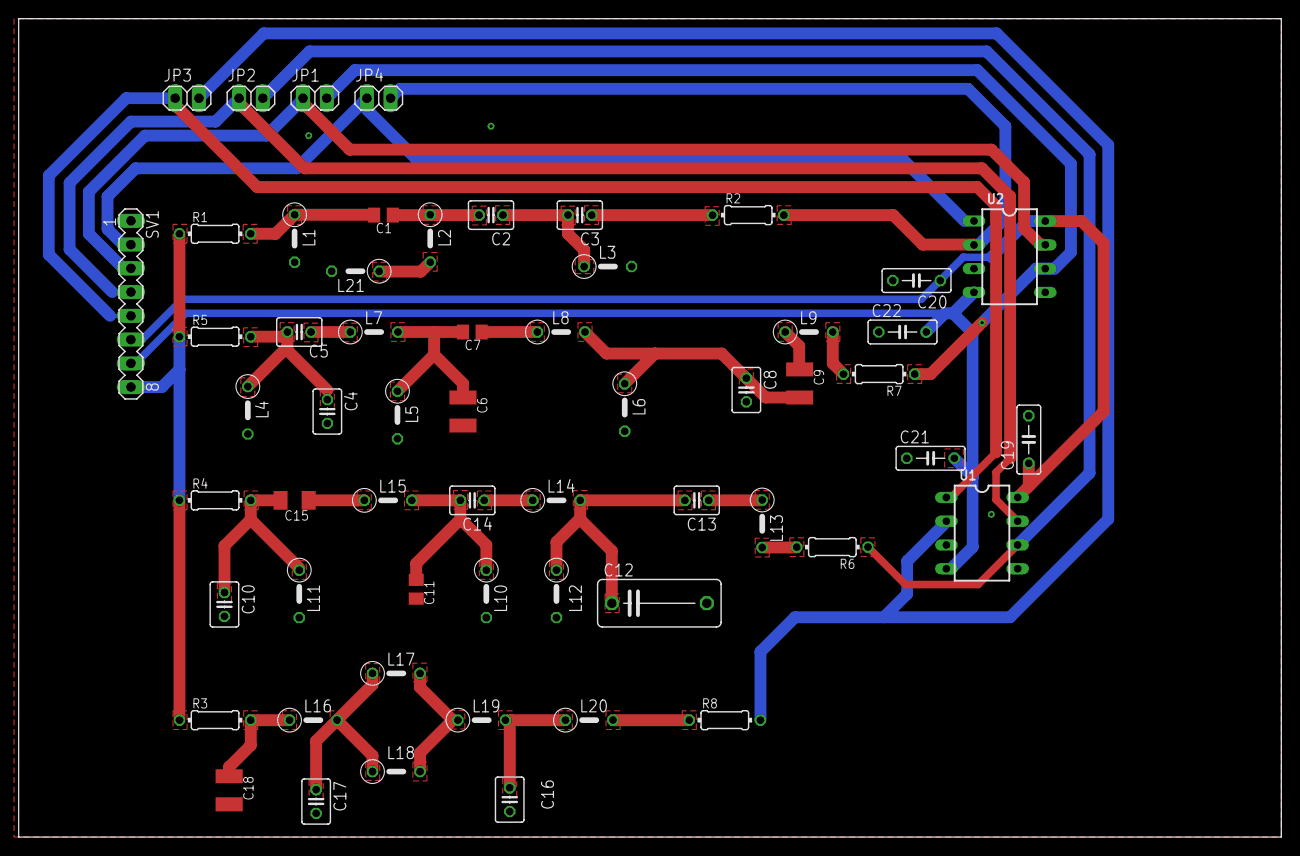
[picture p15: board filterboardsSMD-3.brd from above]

Board: 2 copper layers, 135.0 x 87.5 mm, 58 parts (0 on the bottom side), 36 nets.

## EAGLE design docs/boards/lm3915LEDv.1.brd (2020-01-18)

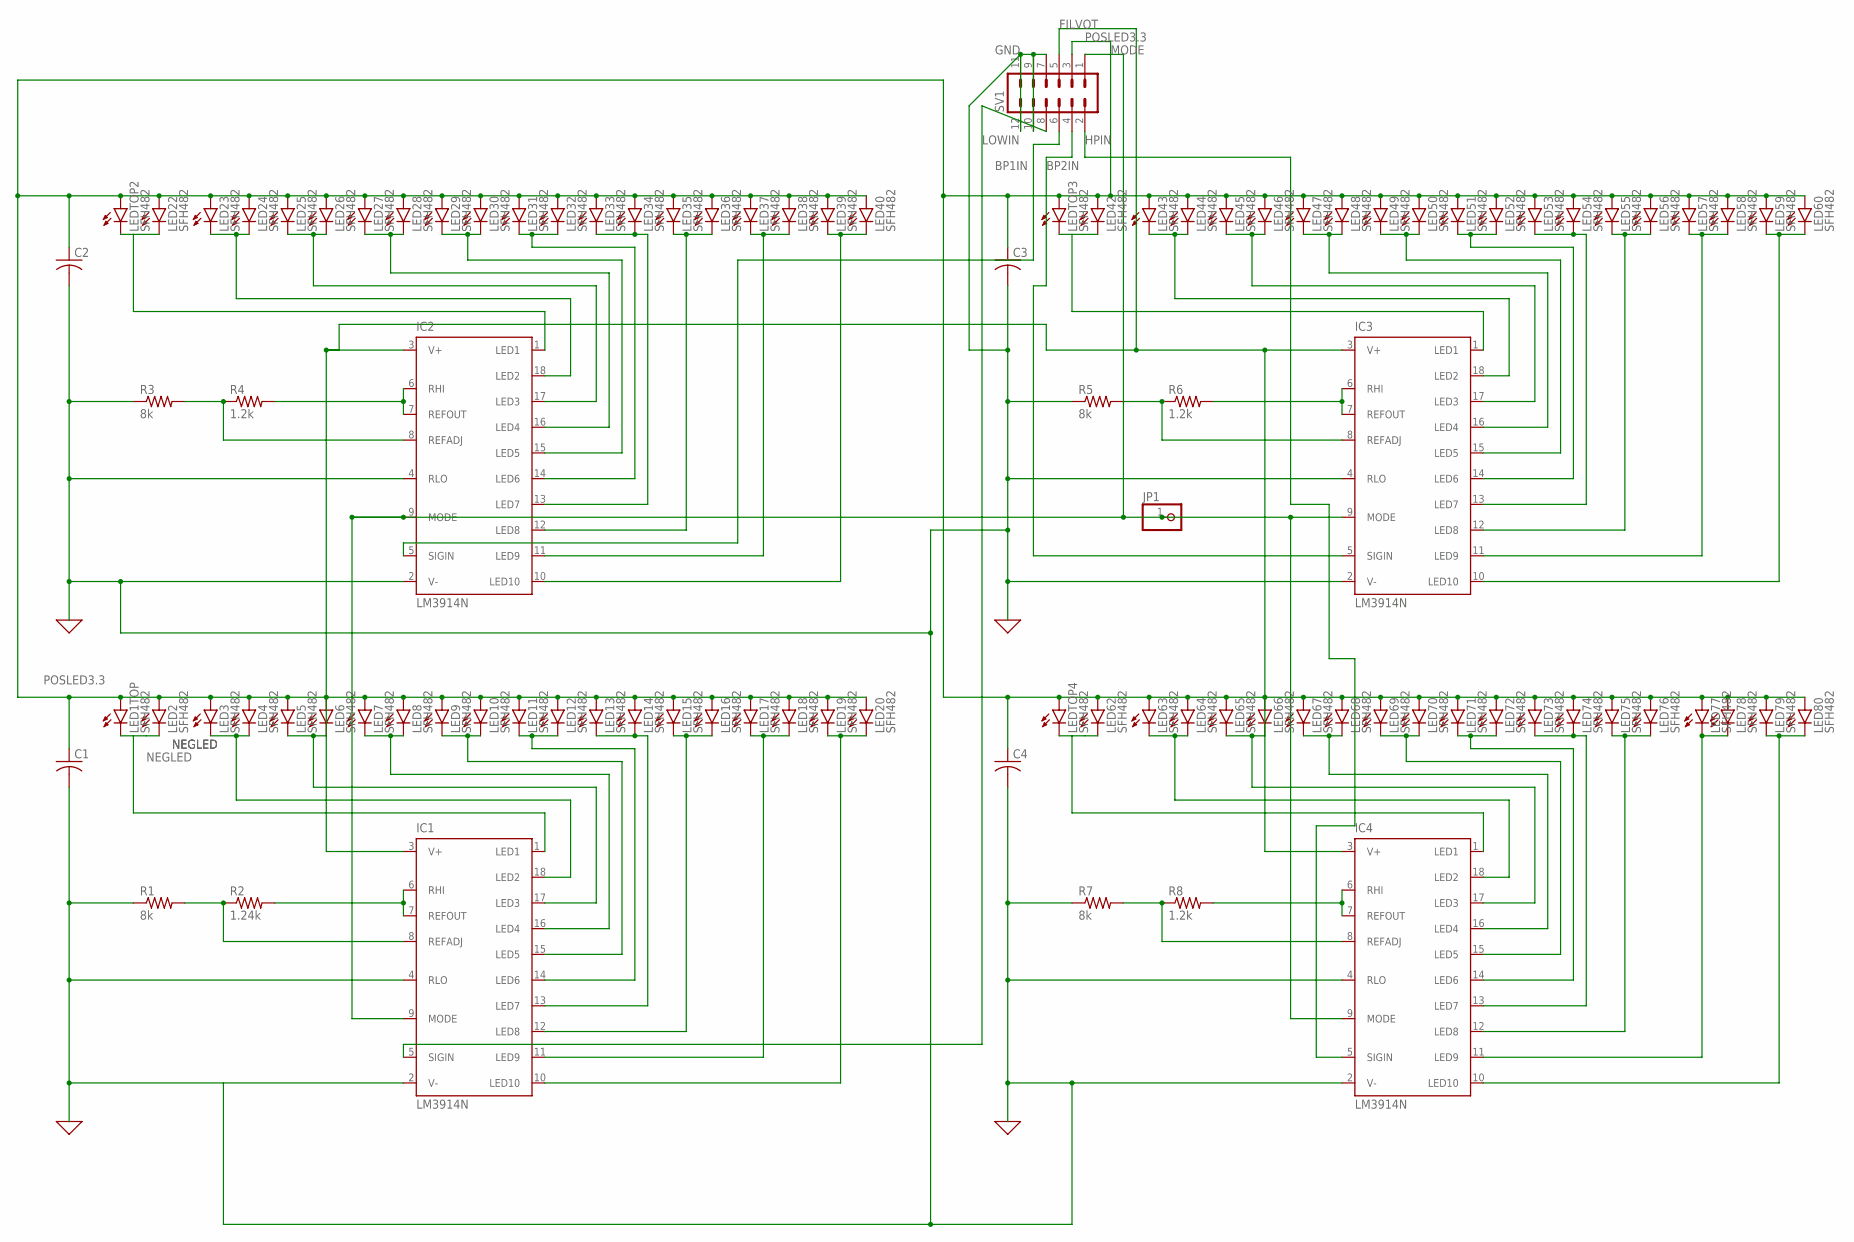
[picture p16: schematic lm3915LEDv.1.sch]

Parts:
C1, C2, C3, C4: C-US025-030X050; C025-030X050
IC1, IC2, IC3, IC4: LM3914N; DIL18
JP1: PINHD-1X1; 1X01
LED1TOP, LED2, LED3, LED4, LED5, LED6, LED7, LED8, LED9, LED10, LED11, LED12, LED13, LED14, LED15, LED16, LED17, LED18, LED19, LED20, LED22, LED23, LED24, LED25, LED26, LED27, LED28, LED29, LED30, LED31, LED32, LED33, LED34, LED35, LED36, LED37, LED38, LED39, LED40, LED42, LED43, LED44, LED45, LED46, LED47, LED48, LED49, LED50, LED51, LED52, LED53, LED54, LED55, LED56, LED57, LED58, LED59, LED60, LED62, LED63, LED64, LED65, LED66, LED67, LED68, LED69, LED70, LED71, LED72, LED73, LED74, LED75, LED76, LED77, LED78, LED79, LED80: SFH482
LEDTOP2, LEDTOP3, LEDTOP4: SFH482
R1, R3, R5, R7: 8k; 0207/10
R2: 1.24k; 0207/10
R4, R6, R8: 1.2k; 0207/10
SV1: MA06-2

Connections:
BP1IN: IC2.5 (SIGIN), SV1.6
BP2IN: IC3.5 (SIGIN), SV1.4
FILVOT: IC1.3 (V+), IC2.3 (V+), IC3.3 (V+), IC4.3 (V+), SV1.5
GND: C1.2, C2.2, C3.2, C4.2, IC1.2 (V-), IC1.4 (RLO), IC2.2 (V-), IC2.4 (RLO), IC3.2 (V-), IC3.4 (RLO), IC4.2 (V-), IC4.4 (RLO), R1.1, R3.1, R5.1, R7.1, SV1.7, SV1.9, SV1.10, SV1.11, SV1.12
HPIN: IC4.5 (SIGIN), SV1.2
LOWIN: IC1.5 (SIGIN), SV1.8
MODE: IC1.9 (MODE), IC2.9 (MODE), IC3.9 (MODE), IC4.9 (MODE), JP1.1, SV1.1
unnamed: IC1.18 (LED2), LED3.K (C), LED4.K (C)
unnamed: IC1.17 (LED3), LED5.K (C), LED6.K (C)
unnamed: IC1.16 (LED4), LED7.K (C), LED8.K (C)
unnamed: IC1.15 (LED5), LED9.K (C), LED10.K (C)
unnamed: IC1.14 (LED6), LED11.K (C), LED12.K (C)
unnamed: IC1.13 (LED7), LED13.K (C), LED14.K (C)
unnamed: IC1.12 (LED8), LED15.K (C), LED16.K (C)
unnamed: IC1.11 (LED9), LED17.K (C), LED18.K (C)
unnamed: IC1.10 (LED10), LED19.K (C), LED20.K (C)
unnamed: IC4.1 (LED1), LED62.K (C), LEDTOP4.K (C)
unnamed: IC2.1 (LED1), LED22.K (C), LEDTOP2.K (C)
unnamed: IC2.18 (LED2), LED23.K (C), LED24.K (C)
unnamed: IC2.17 (LED3), LED25.K (C), LED26.K (C)
unnamed: IC2.16 (LED4), LED27.K (C), LED28.K (C)
unnamed: IC2.15 (LED5), LED29.K (C), LED30.K (C)
unnamed: IC1.6 (RHI), IC1.7 (REFOUT), R2.2
unnamed: IC1.8 (REFADJ), R1.2, R2.1
unnamed: IC2.14 (LED6), LED31.K (C), LED32.K (C)
unnamed: IC2.13 (LED7), LED33.K (C), LED34.K (C)
unnamed: IC2.12 (LED8), LED35.K (C), LED36.K (C)
unnamed: IC2.11 (LED9), LED37.K (C), LED38.K (C)
unnamed: IC2.10 (LED10), LED39.K (C), LED40.K (C)
unnamed: IC2.6 (RHI), IC2.7 (REFOUT), R4.2
unnamed: IC2.8 (REFADJ), R3.2, R4.1
unnamed: IC3.1 (LED1), LED42.K (C), LEDTOP3.K (C)
unnamed: IC3.18 (LED2), LED43.K (C), LED44.K (C)
unnamed: IC3.17 (LED3), LED45.K (C), LED46.K (C)
unnamed: IC3.16 (LED4), LED47.K (C), LED48.K (C)
unnamed: IC3.15 (LED5), LED49.K (C), LED50.K (C)
unnamed: IC3.14 (LED6), LED51.K (C), LED52.K (C)
unnamed: IC3.13 (LED7), LED53.K (C), LED54.K (C)
unnamed: IC3.12 (LED8), LED55.K (C), LED56.K (C)
unnamed: IC3.11 (LED9), LED57.K (C), LED58.K (C)
unnamed: IC3.10 (LED10), LED59.K (C), LED60.K (C)
unnamed: IC3.6 (RHI), IC3.7 (REFOUT), R6.2
unnamed: IC3.8 (REFADJ), R5.2, R6.1
unnamed: IC4.18 (LED2), LED63.K (C), LED64.K (C)
unnamed: IC4.17 (LED3), LED65.K (C), LED66.K (C)
unnamed: IC4.16 (LED4), LED67.K (C), LED68.K (C)
unnamed: IC4.15 (LED5), LED69.K (C), LED70.K (C)
unnamed: IC4.14 (LED6), LED71.K (C), LED72.K (C)
unnamed: IC4.13 (LED7), LED73.K (C), LED74.K (C)
unnamed: IC4.12 (LED8), LED75.K (C), LED76.K (C)
unnamed: IC4.11 (LED9), LED77.K (C), LED78.K (C)
unnamed: IC4.10 (LED10), LED79.K (C), LED80.K (C)
unnamed: IC4.6 (RHI), IC4.7 (REFOUT), R8.2
unnamed: IC4.8 (REFADJ), R7.2, R8.1
NEGLED: IC1.1 (LED1), LED1TOP.K (C), LED2.K (C)
POSLED3.3: C1.1, C2.1, C3.1, C4.1, LED1TOP.A, LED2.A, LED3.A, LED4.A, LED5.A, LED6.A, LED7.A, LED8.A, LED9.A, LED10.A, LED11.A, LED12.A, LED13.A, LED14.A, LED15.A, LED16.A, LED17.A, LED18.A, LED19.A, LED20.A, LED22.A, LED23.A, LED24.A, LED25.A, LED26.A, LED27.A, LED28.A, LED29.A, LED30.A, LED31.A, LED32.A, LED33.A, LED34.A, LED35.A, LED36.A, LED37.A, LED38.A, LED39.A, LED40.A, LED42.A, LED43.A, LED44.A, LED45.A, LED46.A, LED47.A, LED48.A, LED49.A, LED50.A, LED51.A, LED52.A, LED53.A, LED54.A, LED55.A, LED56.A, LED57.A, LED58.A, LED59.A, LED60.A, LED62.A, LED63.A, LED64.A, LED65.A, LED66.A, LED67.A, LED68.A, LED69.A, LED70.A, LED71.A, LED72.A, LED73.A, LED74.A, LED75.A, LED76.A, LED77.A, LED78.A, LED79.A, LED80.A, LEDTOP2.A, LEDTOP3.A, LEDTOP4.A, SV1.3

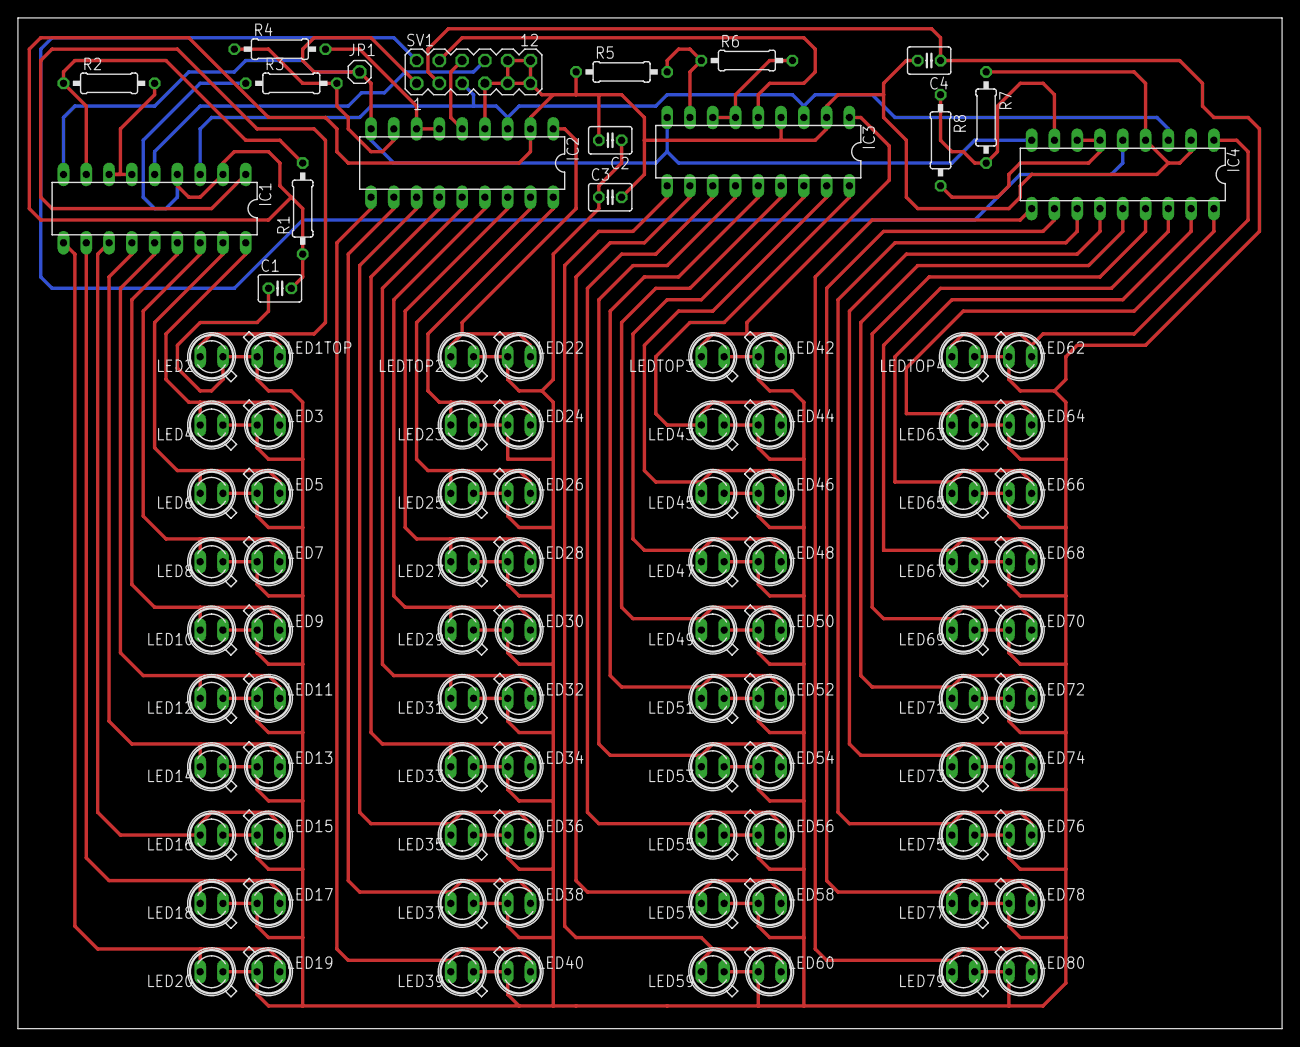
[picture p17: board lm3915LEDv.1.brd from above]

Board: 2 copper layers, 140.9 x 112.7 mm, 98 parts (0 on the bottom side), 56 nets.

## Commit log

2019-07-17 matlab high pass filter
2019-07-17 insert basic transfer function info
2019-07-17 insert basic component calc info
2019-07-17 insert basic transfer function bp2
2019-07-17 insert basic component calc info hp
2019-07-17 insert basic transfer function hp info

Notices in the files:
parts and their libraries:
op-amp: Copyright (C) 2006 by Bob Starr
